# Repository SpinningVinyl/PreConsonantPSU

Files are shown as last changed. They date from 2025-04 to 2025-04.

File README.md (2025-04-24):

# PreConsonant PSU

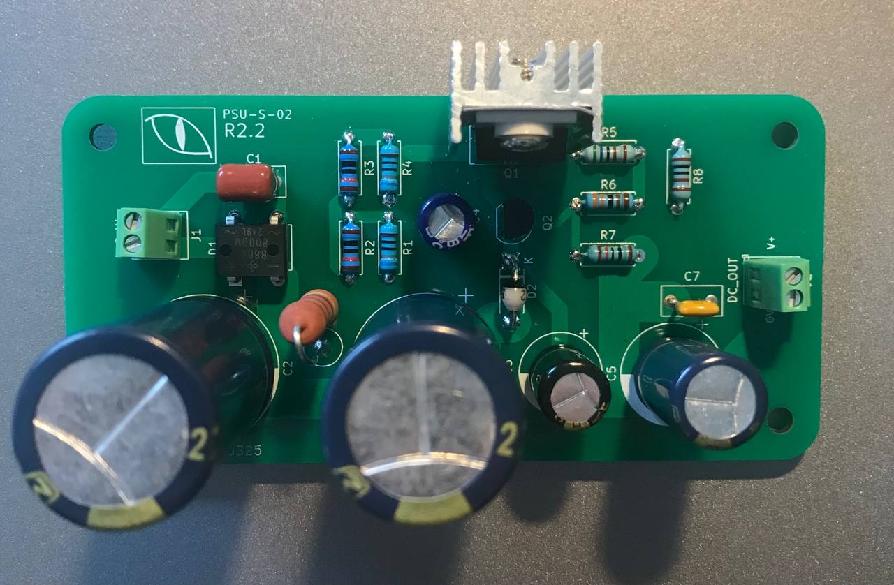
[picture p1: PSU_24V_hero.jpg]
Assembled PCB


### Basic Information

This is a 24V PSU I designed for use with the [PreConsonant phono preamplifier](https://github.com/SpinningVinyl/PreConsonant2021). It is basically a discrete feedback regulator with an error amplifier consisting of a single transistor (Q2 on the circuit diagram). It is designed to be used with a 24V transformer because I wanted to use an off-the-shelf 24V AC wall wart to power my phono preamplifier build. Since transformers typically have no-load output voltage that can be up to 20% higher than their rated voltage under full load, it was going to be too high for a standard 3-pin voltage regulator IC (e.g. LM7824).

### Technical specifications

 - Input voltage: between 21 and 30V AC (with the specified components)
 - Output voltage: approx. 24V DC
 - Load regulation: less than 1% at 100mA output current (component values have been calculated for output currents up to 500mA)
 - Ripple and noise: more than 60dB below the output level
 
### Documentation
The documentation (bill of materials and full circuit diagram) is located in the `docs` folder.

### Status of the project

The project has been built and tested.

### License
See the `LICENSE` file for details.

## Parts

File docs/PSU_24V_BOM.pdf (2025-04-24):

PSU_24V_BOM

Reference | Value | Footprint | Qty
C1 | 100n | MKT, 250V, pin spacing 5mm | 1
C7 | 100n | Ceramic or MKT, 50V, pin spacing 5mm | 1
C2,C3 | 2200u | Electrolytic capacitor, 50V, D18.0mm, pin spacing 7.50mm | 2
C4 | 10u | Non-polar electrolytic capacitor, 50V | 1
C5 | 100u | Electrolytic capacitor, 35V, D10.0mm, pin spacing 5.00mm | 1
C6 | 470u | Electrolytic capacitor, 35V, D12.5mm, pin spacing 5.00mm | 1
C8 | 4u7 | Electrolytic capacitor, 25V, D4.0mm, pin spacing 2.00mm | 1
D1 | B80C800DM | Vishay B80C800DM silicon diode bridge | 1
D2 | 12V | Zener diode, 12V | 1
J1 | AC_IN | Terminal block, 2 pin, 5mm spacing | 1
J2 | DC_OUT | Terminal block, 2 pin, 5mm spacing | 1
Q1 | TIP122 | TO-220 Darlington | 1
Q2 | BC546B | Any NPN with Vce > 30V and CBE pinout, e.g. BC337 | 1
R1,R4 | 680R | 0207 1% metal film | 2
R2,R3 | 120R | 0207 1% metal film | 2
R5 | 5k6 | 0207 1% metal film | 1
R6 | 3k3 | 0207 1% metal film | 1
R7 | 10k | 0207 1% metal film | 1
R8 | 1k2 | 0207 1% metal film | 1
R9 | 4R7 | 3W power resistor, axial | 1

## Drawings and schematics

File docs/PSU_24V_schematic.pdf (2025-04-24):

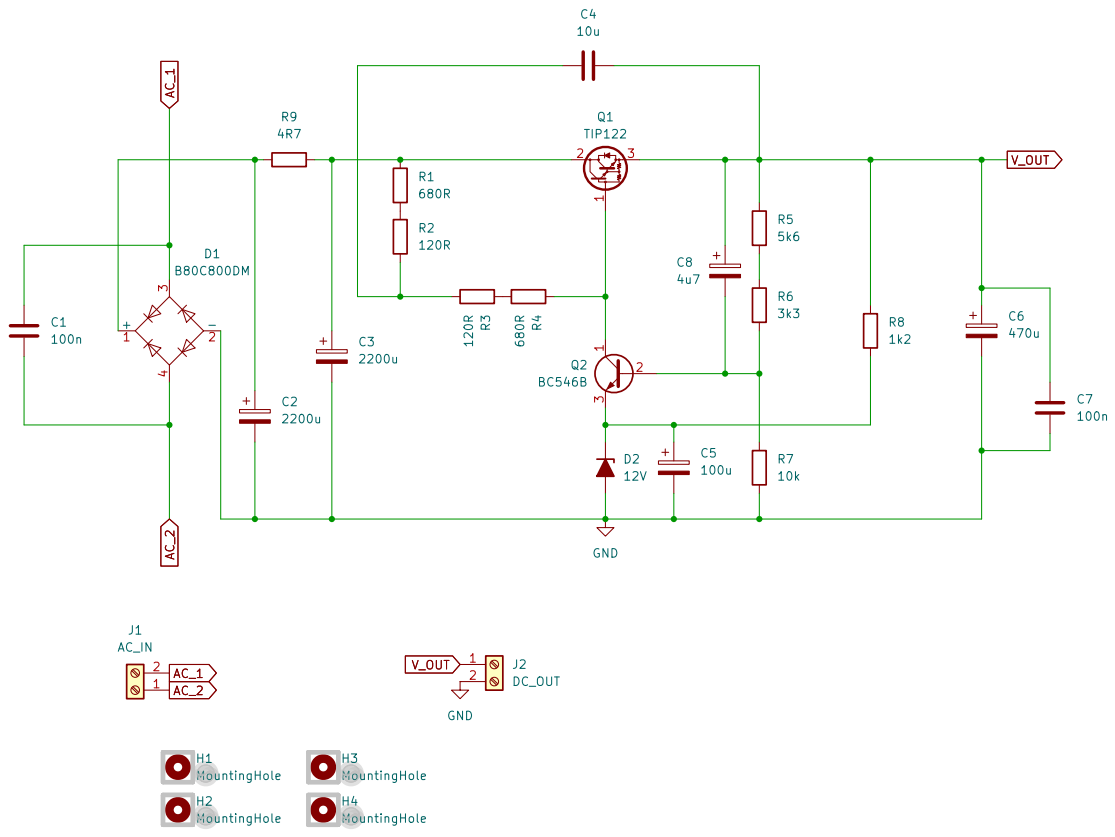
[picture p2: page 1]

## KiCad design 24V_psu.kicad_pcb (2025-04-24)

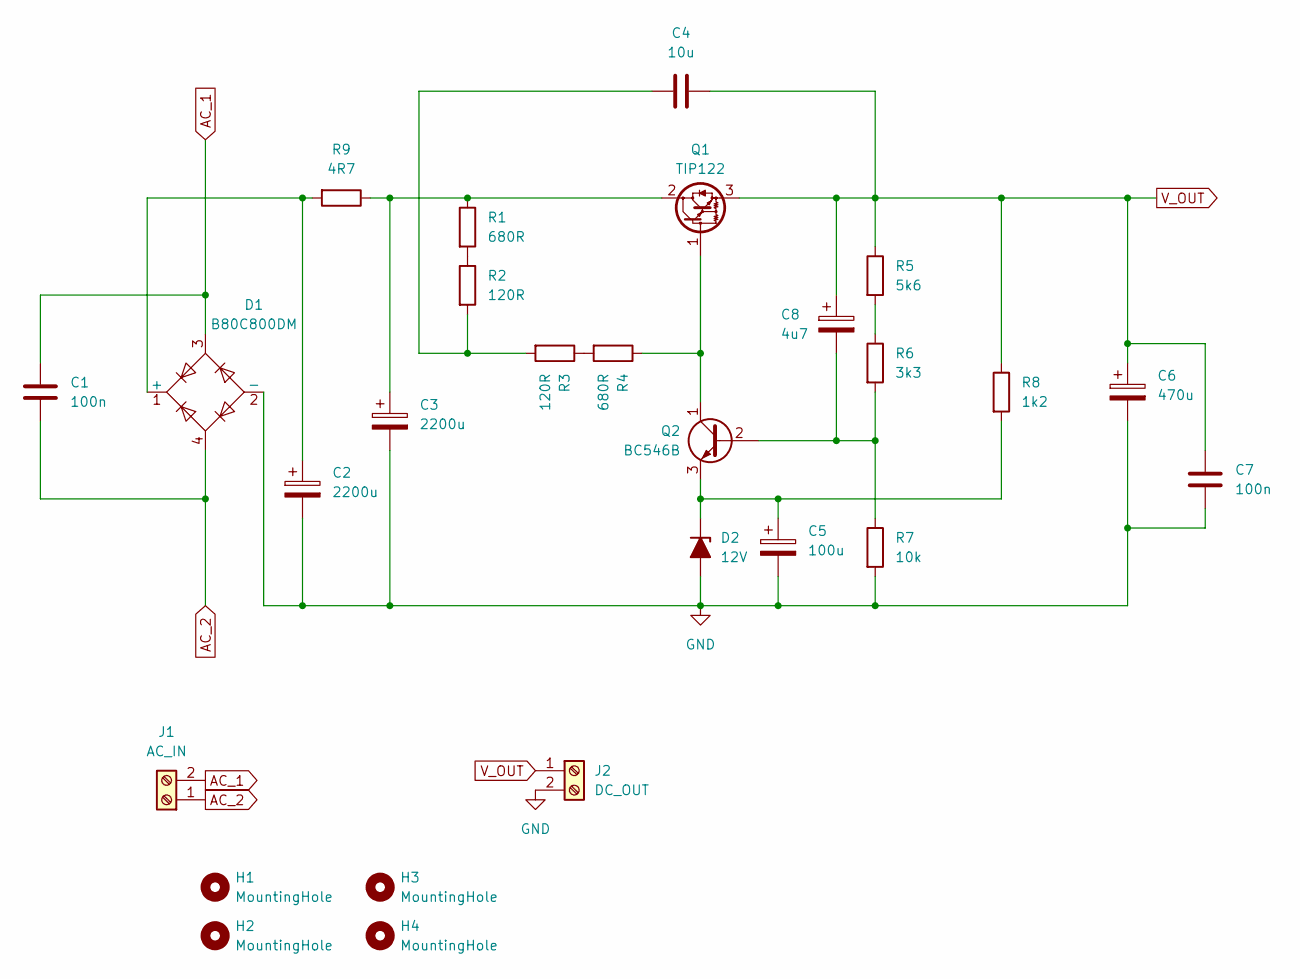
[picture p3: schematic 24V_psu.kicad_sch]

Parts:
C1, C7: 100n; C_Rect_L7.2mm_W3.5mm_P5.00mm_FKS2_FKP2_MKS2_MKP2
C2, C3: 2200u; CP_Radial_D18.0mm_P7.50mm
C4: 10u; C_Radial_D5.0mm_H11.0mm_P2.00mm
C5: 100u; CP_Radial_D10.0mm_P5.00mm
C6: 470u; CP_Radial_D12.5mm_P5.00mm
C8: 4u7; CP_Radial_D4.0mm_P2.00mm
D1: B80C800DM; Diode_Bridge_DIP-4_W7.62mm_P5.08mm
D2: 12V; D_DO-41_SOD81_P7.62mm_Horizontal
H1, H2, H3, H4: MountingHole; MountingHole_3.2mm_M3
J1: AC_IN; TerminalBlock_MaiXu_MX126-5.0-02P_1x02_P5.00mm
J2: DC_OUT; TerminalBlock_MaiXu_MX126-5.0-02P_1x02_P5.00mm
Q1: TIP122; TO-220-3_Vertical
Q2: BC546B; TO-92_HandSolder
R1, R4: 680R; R_Axial_DIN0207_L6.3mm_D2.5mm_P7.62mm_Horizontal
R2, R3: 120R; R_Axial_DIN0207_L6.3mm_D2.5mm_P7.62mm_Horizontal
R5: 5k6; R_Axial_DIN0207_L6.3mm_D2.5mm_P7.62mm_Horizontal
R6: 3k3; R_Axial_DIN0207_L6.3mm_D2.5mm_P7.62mm_Horizontal
R7: 10k; R_Axial_DIN0207_L6.3mm_D2.5mm_P7.62mm_Horizontal
R8: 1k2; R_Axial_DIN0207_L6.3mm_D2.5mm_P7.62mm_Horizontal
R9: 4R7; R_Axial_DIN0414_L11.9mm_D4.5mm_P5.08mm_Vertical

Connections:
AC_1: C1.1, D1.3, J1.2
AC_2: C1.2, D1.4, J1.1
GND: C2.2, C3.2, C5.2, C6.2, C7.2, D1.2 (-), D2.2 (A), J2.2, R7.2
unnamed: C4.2, R2.2, R3.2
unnamed: C2.1, D1.1 (+), R9.2
unnamed: C5.1, D2.1 (K), Q2.3 (E), R8.2
unnamed: Q1.1 (B), Q2.1 (C), R4.1
unnamed: C3.1, Q1.2 (C), R1.1, R9.1
unnamed: C8.2, Q2.2 (B), R6.2, R7.1
unnamed: R1.2, R2.1
unnamed: R3.1, R4.2
unnamed: R5.2, R6.1
V_OUT: C4.1, C6.1, C7.1, C8.1, J2.1, Q1.3 (E), R5.1, R8.1

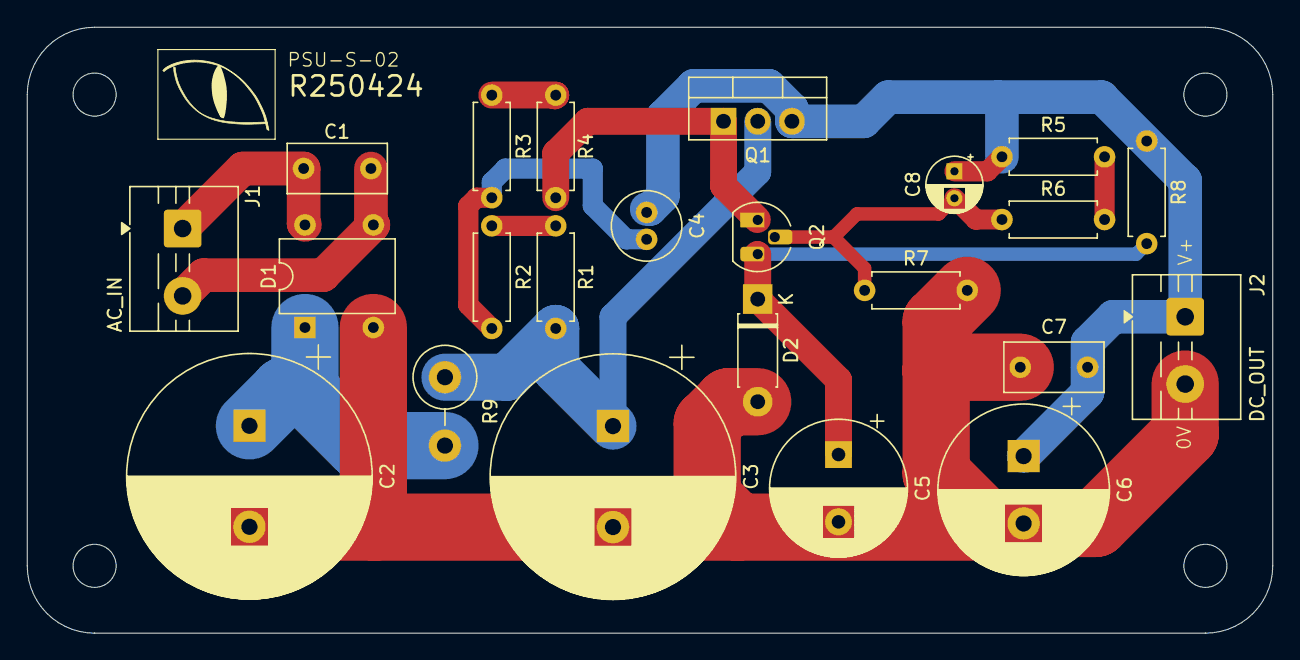
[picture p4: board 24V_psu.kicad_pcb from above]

Board: 2 copper layers, 92.5 x 45.0 mm, 27 parts (0 on the bottom side), 13 nets.

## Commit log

2025-04-24 Initial public release
    [24V_psu.kicad_pcb, 24V_psu.kicad_sch]
2025-04-24 Change C4 footprint to non-polarized
    [24V_psu.kicad_pcb, 24V_psu.kicad_sch]
2025-04-24 Move R5, R6 and R8 to provide space for a heatsink
    [24V_psu.kicad_pcb]
2025-04-24 Add C8 for slightly improved ripple rejection
    [24V_psu.kicad_pcb, 24V_psu.kicad_sch]
2025-04-24 Change J1 and J2 to 5mm pitch
    [24V_psu.kicad_pcb, 24V_psu.kicad_sch]
2025-04-24 Rotate R9 around
    [24V_psu.kicad_pcb, 24V_psu.kicad_sch]
